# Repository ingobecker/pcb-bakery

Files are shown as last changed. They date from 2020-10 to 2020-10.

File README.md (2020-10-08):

# SMD Reflow oven

I converted an old bread machine into a reflow oven. I replaced the original
control board with a STM32F103 bluepill board, a 2 chanel relay board as well
as a type k thermocouple.  The components for the conversion coast around 10€
in total and it should be possible to apply them to most bread machines,
electric BBQs, raclette grills etc.

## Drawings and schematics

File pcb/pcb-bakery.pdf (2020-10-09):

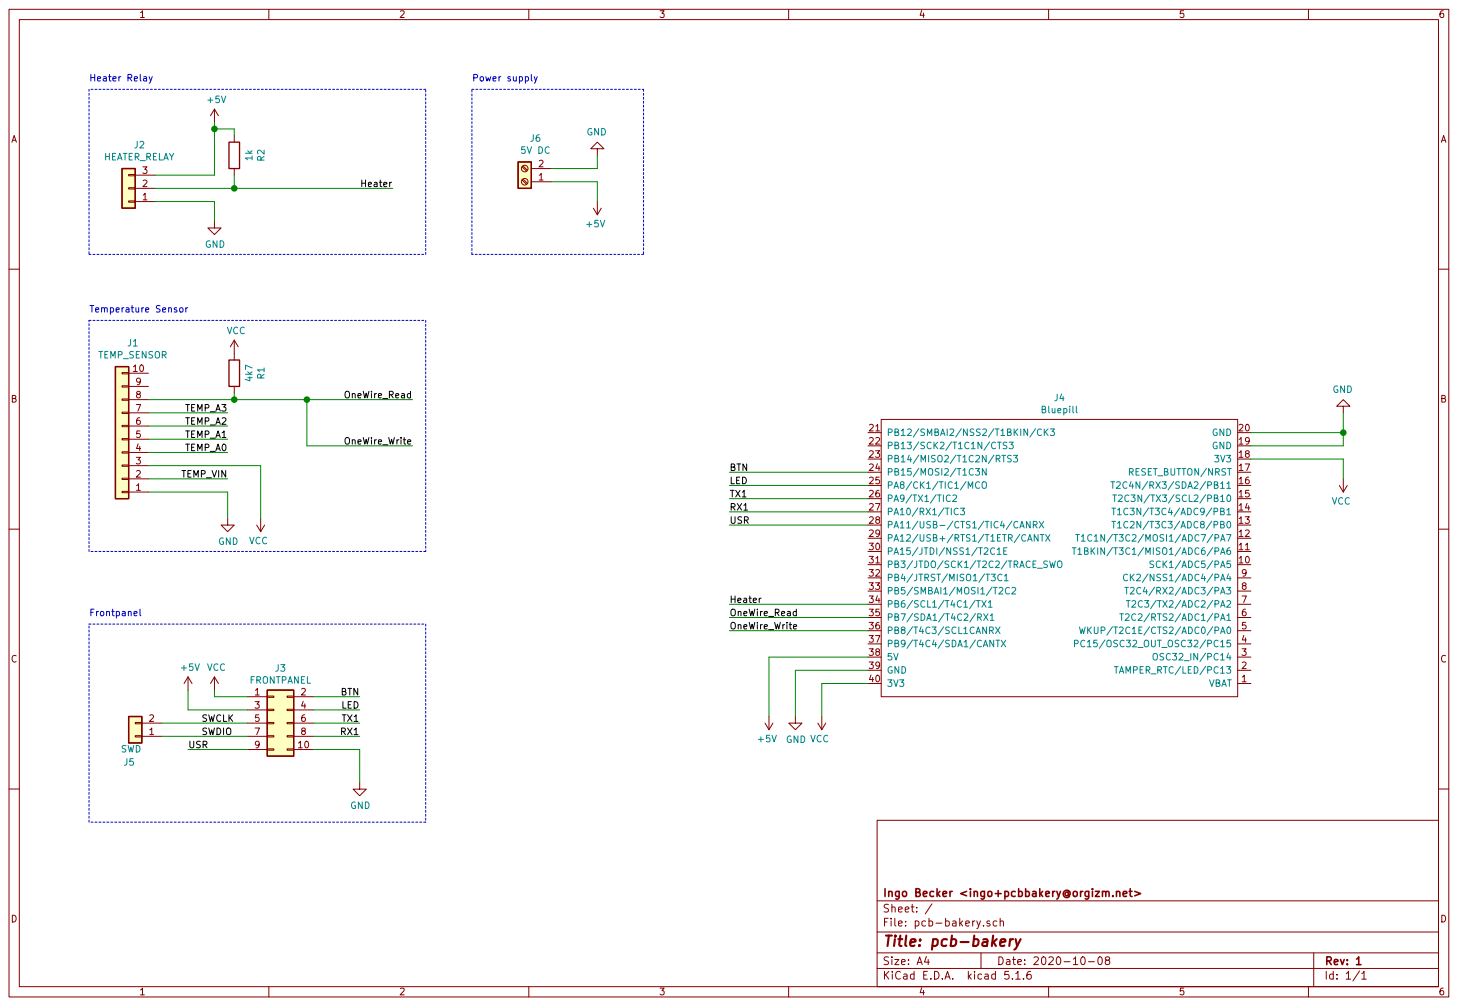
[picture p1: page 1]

Ingo Becker <ingo+pcbbakery@orgizm.net>
File: pcb-bakery.sch Sheet: /
Id: 1/1 Title: pcb-bakery

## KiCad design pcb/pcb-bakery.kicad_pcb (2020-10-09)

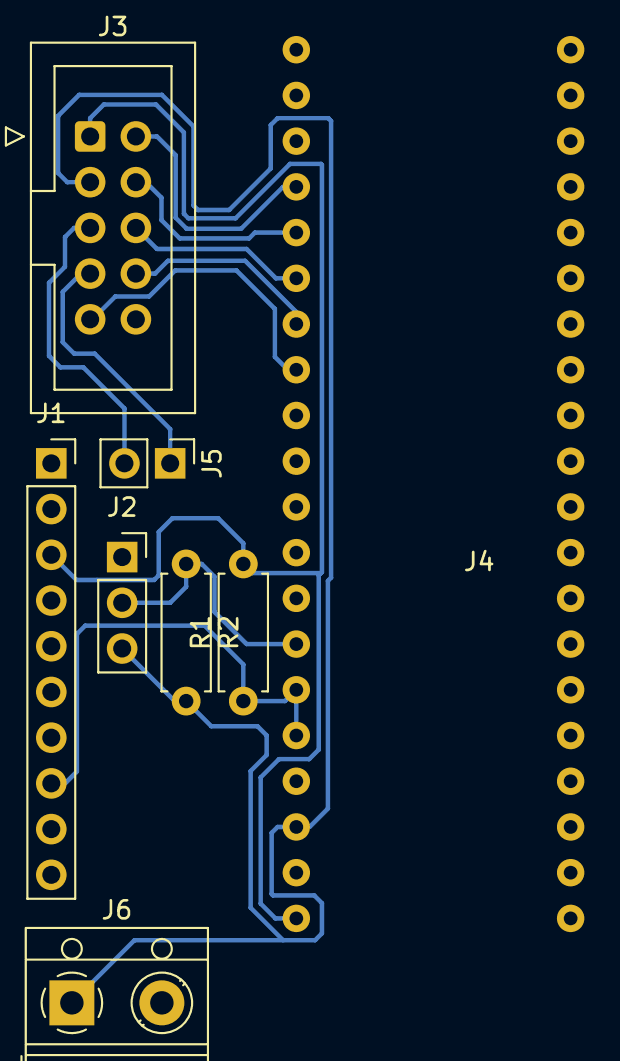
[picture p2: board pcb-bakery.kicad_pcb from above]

Board: 2 copper layers, 8 parts (0 on the bottom side), 12 nets.

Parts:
J1: TEMP_SENSOR; PinSocket_1x10_P2.54mm_Vertical
J2: HEATER_RELAY; PinSocket_1x03_P2.54mm_Vertical
J3: FRONTPANEL; IDC-Header_2x05_P2.54mm_Vertical
J4: Bluepill
J5: SWD; PinHeader_1x02_P2.54mm_Vertical
J6: 5V DC; TerminalBlock_RND_205-00012_1x02_P5.00mm_Horizontal
R1: 4k7; R_Axial_DIN0207_L6.3mm_D2.5mm_P7.62mm_Horizontal
R2: 1k; R_Axial_DIN0207_L6.3mm_D2.5mm_P7.62mm_Horizontal

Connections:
+5V: J2.3, J3.3, J4.38, J6.1, R2.2
/BTN: J3.2, J4.24
/Heater: J2.2, J4.34, R2.1
/LED: J3.4, J4.25
/OneWire_Read: J1.8, J4.35, J4.36, R1.1
/RX1: J3.8, J4.27
/SWCLK: J3.5, J5.2
/SWDIO: J3.7, J5.1
/TX1: J3.6, J4.26
/USR: J3.9, J4.28
GND: J1.1, J2.1, J3.10, J4.19, J4.20, J4.39, J6.2
VCC: J1.3, J3.1, J4.18, J4.40, R1.2

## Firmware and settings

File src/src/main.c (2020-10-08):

#include <stdio.h>
#include <errno.h>
#include <libopencm3/stm32/gpio.h>
#include <libopencm3/stm32/rtc.h>
#include <libopencm3/stm32/usart.h>
#include "config.h"
#include "newlibio.h"
#include "bluepill.h"
#include "temperature.h"

int main(void)
{
	rcc_clock_setup_in_hse_8mhz_out_72mhz();
	bluepill_uart_setup();

	// setup bluepill LED
	bluepill_led_setup();

	// setup frontpanel button
	rcc_periph_clock_enable(BTN_RCC_BIT);
	gpio_set_mode(BTN_PORT, GPIO_MODE_INPUT,
		GPIO_CNF_INPUT_PULL_UPDOWN, BTN_PIN);

	// setup relay
	rcc_periph_clock_enable(RELAY_RCC_BIT);
	gpio_set_mode(RELAY_OUTPUT_PORT, GPIO_MODE_OUTPUT_2_MHZ,
		GPIO_CNF_OUTPUT_OPENDRAIN, RELAY_OUTPUT_PIN);

	// setup RTC
	rtc_auto_awake(RCC_LSE, 0x7fff);
	rtc_set_prescale_val(0x7fff);
	rtc_set_counter_val(0);

	// make sure relay is open(heater turned off)
	gpio_set(RELAY_OUTPUT_PORT, RELAY_OUTPUT_PIN);

	// disable led
	gpio_set(BLUEPILL_LED_PORT, BLUEPILL_LED_PIN);

	printf("Baker initialized\r\n");

	int pushed = 0;
	int temp = 0;
	while (1) {
		if(pushed == 0){
			if(gpio_get(BTN_PORT, BTN_PIN) != 0){
				// enable led
				gpio_clear(BLUEPILL_LED_PORT,BLUEPILL_LED_PIN);

				// enable relais
				gpio_clear(RELAY_OUTPUT_PORT, RELAY_OUTPUT_PIN);
				pushed = 1;
			}
		}

		if (pushed) {
			temp = one_wire_read_temp();
			printf("temp: %i\r\n", temp);
			if (temp > 1 && temp < TEMP_MAX) {
			  gpio_toggle(BLUEPILL_LED_PORT, BLUEPILL_LED_PIN);
			} else if (temp >= TEMP_MAX) {
			  gpio_set(BLUEPILL_LED_PORT, BLUEPILL_LED_PIN);
			  // disable relais
			  gpio_set(RELAY_OUTPUT_PORT, RELAY_OUTPUT_PIN);
			  pushed = 0;
			}
		}
	}
	return 0;
}

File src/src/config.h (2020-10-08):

#ifndef _CONFIG_H
#define _CONFIG_H

// Heaters relay config
#define RELAY_OUTPUT_PORT GPIOB
#define RELAY_OUTPUT_PIN GPIO6
#define RELAY_RCC_BIT RCC_GPIOB

// Temperatur sensor one wire config
#define ONE_WIRE_READ_PORT GPIOB
#define ONE_WIRE_READ_PIN GPIO7
#define ONE_WIRE_READ_RCC_BIT RCC_GPIOB

#define ONE_WIRE_WRITE_PORT GPIOB
#define ONE_WIRE_WRITE_PIN GPIO8
#define ONE_WIRE_WRITE_RCC_BIT RCC_GPIOB

#define ONE_WIRE_WRITE_TIMER_RCC RCC_TIM4
#define ONE_WIRE_WRITE_TIMER_RST RST_TIM4
#define ONE_WIRE_WRITE_TIMER TIM4
#define ONE_WIRE_WRITE_TIMER_OC TIM_OC3
#define ONE_WIRE_WRITE_TIMER_CCIF TIM_SR_CC3IF

#define TEMP_MAX 230

// User interface config
#define STATUS_LED_RCC_BIT RCC_GPIOA
#define STATUS_LED_PORT GPIOA
#define STATUS_LED_PIN GPIO8

#define BTN_RCC_BIT RCC_GPIOB
#define BTN_PORT GPIOB
#define BTN_PIN GPIO15

#endif
